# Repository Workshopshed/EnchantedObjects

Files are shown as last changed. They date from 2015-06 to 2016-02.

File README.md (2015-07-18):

# EnchantedObjects
The Enchanted Objects Design Challege asks 15 competitors to enchant an every day object.
http://www.element14.com/community/community/design-challenges/enchanted-objects

# The enchanted cottage
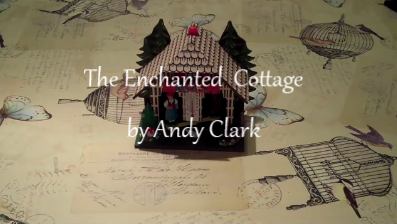
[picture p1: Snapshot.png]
The Enchanted Cottage


This particular enchanted object is right out of the storybooks. Deep in the forest is a small cottage owned by a timeless couple, Hans and Matilda who are doomed never to meet. When it is wet he goes outside but when it is dry she must leave the house.

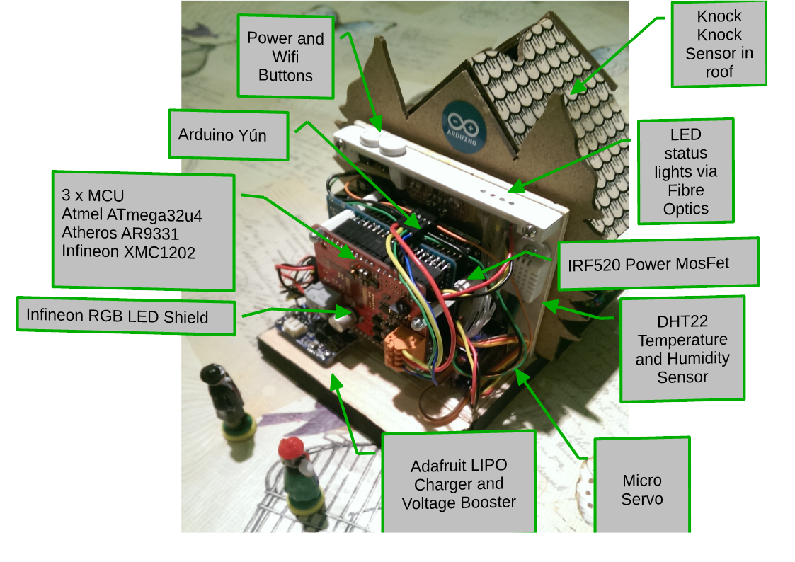
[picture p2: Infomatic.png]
System Overview


Their house may look traditional but is full of state of the art electronics. Thanks to their Arduino Yun they can receive their weather reports from the internet. And rather than their motion being powered by catgut they are now servo assisted. The inside of their house is lit with a colour changing LED which shows the status and temperature.

http://www.element14.com/community/community/design-challenges/enchanted-objects/blog/authors/Workshopshed

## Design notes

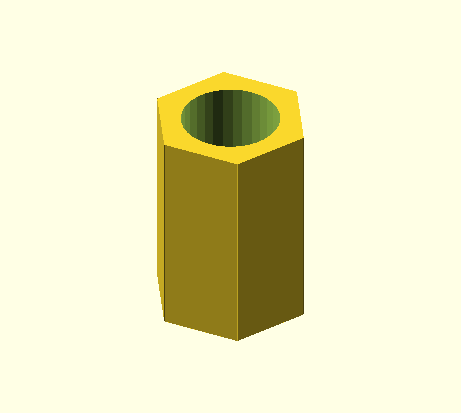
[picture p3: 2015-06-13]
Mechanics/Spacer.png

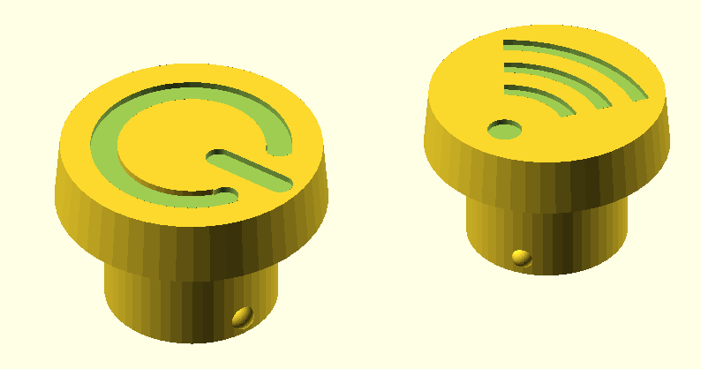
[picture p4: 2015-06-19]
Mechanics/Buttons.png

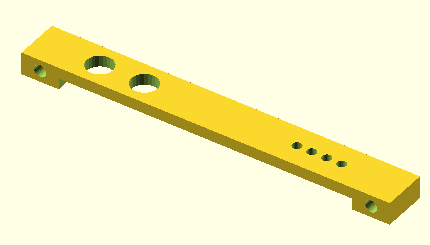
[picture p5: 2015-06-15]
Mechanics/TopPanel.png

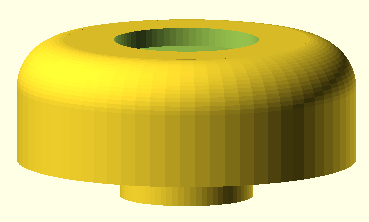
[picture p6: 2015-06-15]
Mechanics/MagnetHousing.png

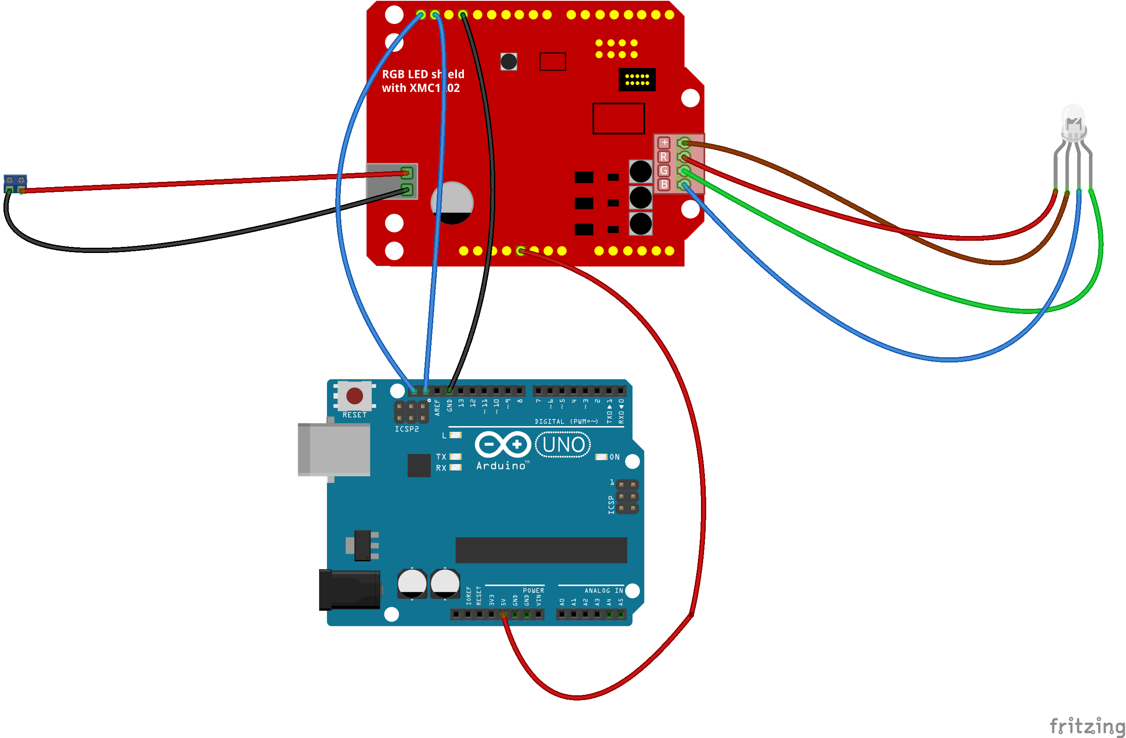
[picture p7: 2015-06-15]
Electronics/RGB Demo_bb.png

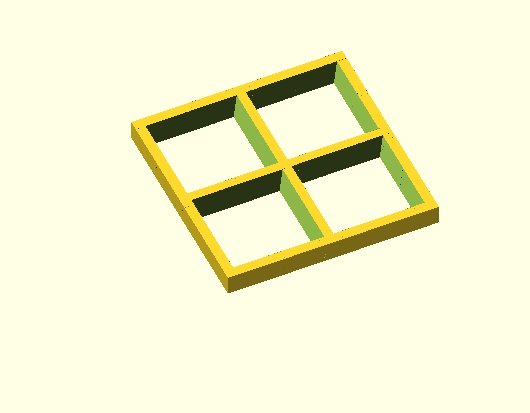
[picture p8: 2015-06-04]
Mechanics/WindowFrame.png

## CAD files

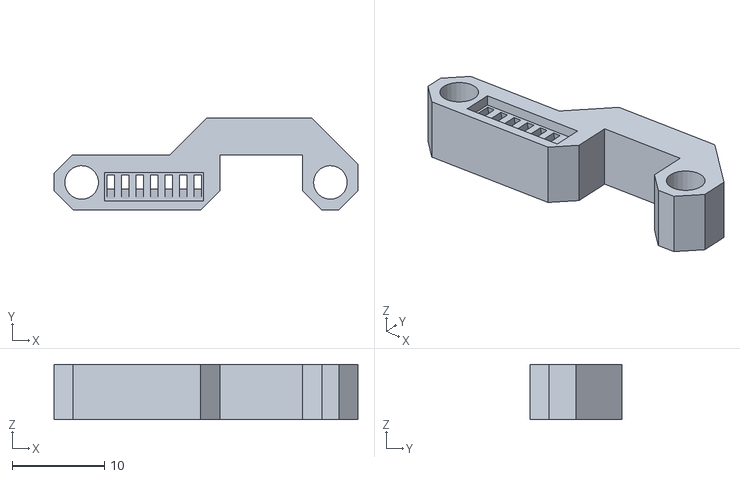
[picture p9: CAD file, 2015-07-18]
Mechanics/FibreHousing.stl
33.0 x 10.0 x 6.00

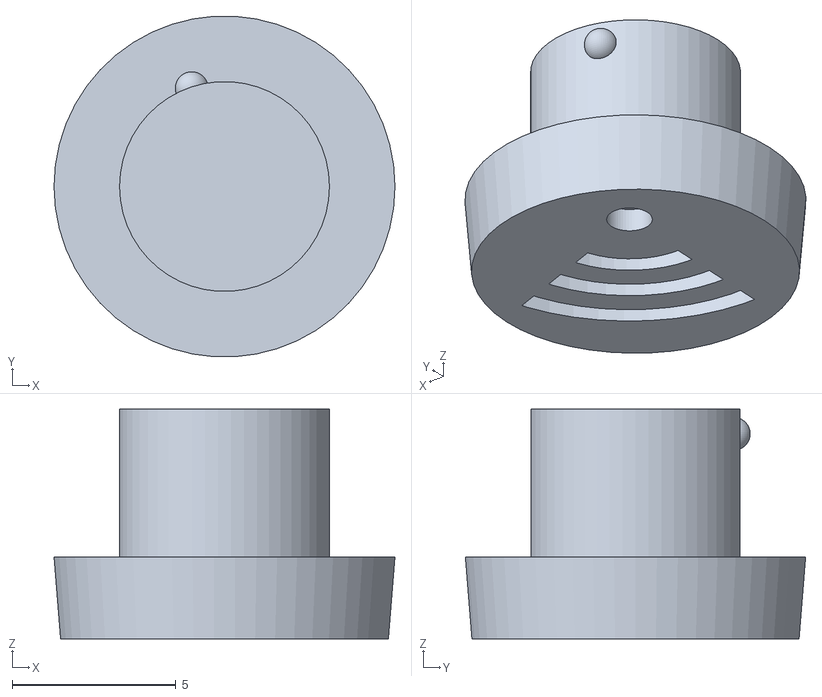
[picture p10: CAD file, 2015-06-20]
Mechanics/ButtonWifi.stl
10.4 x 10.4 x 7.00

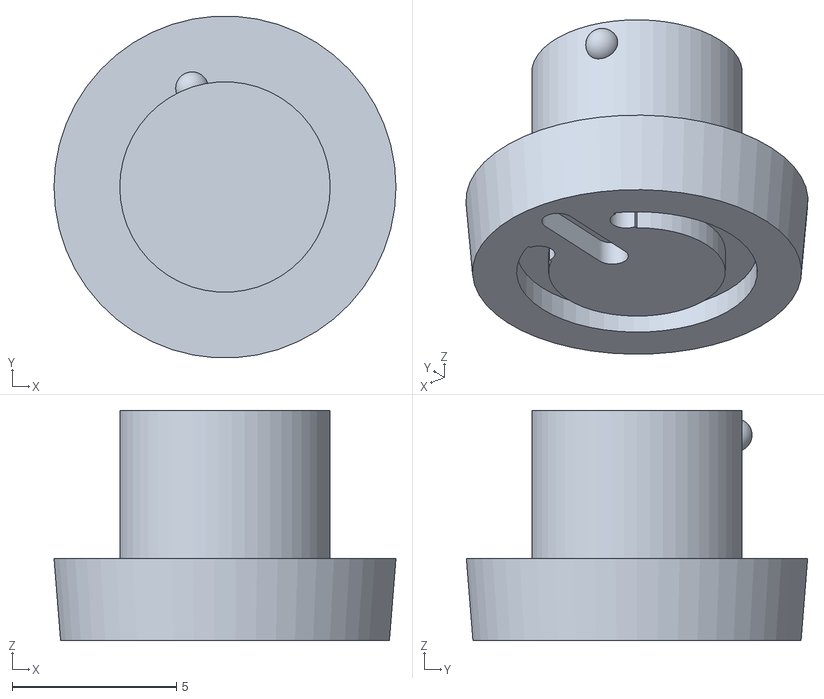
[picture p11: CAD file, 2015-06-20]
Mechanics/ButtonPower.stl
10.4 x 10.4 x 7.00

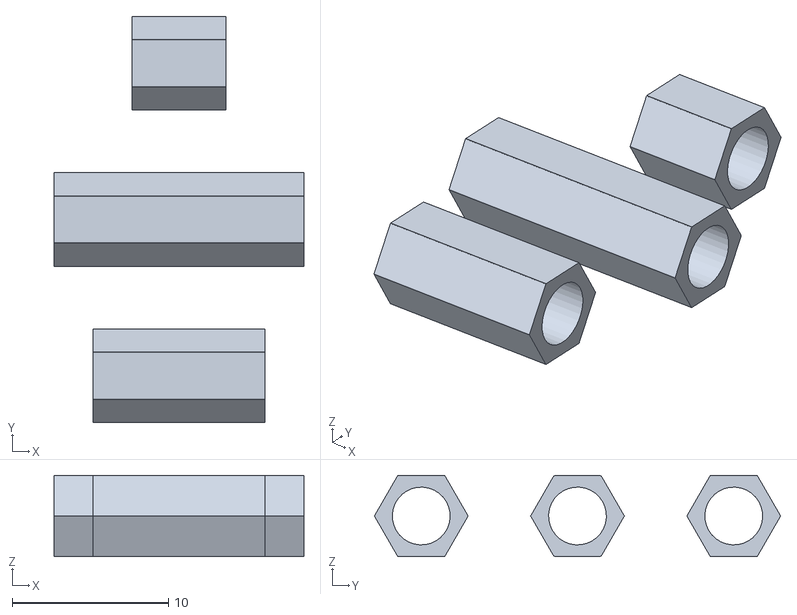
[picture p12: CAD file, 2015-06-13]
Mechanics/Spacers.stl
16.0 x 26.0 x 5.20

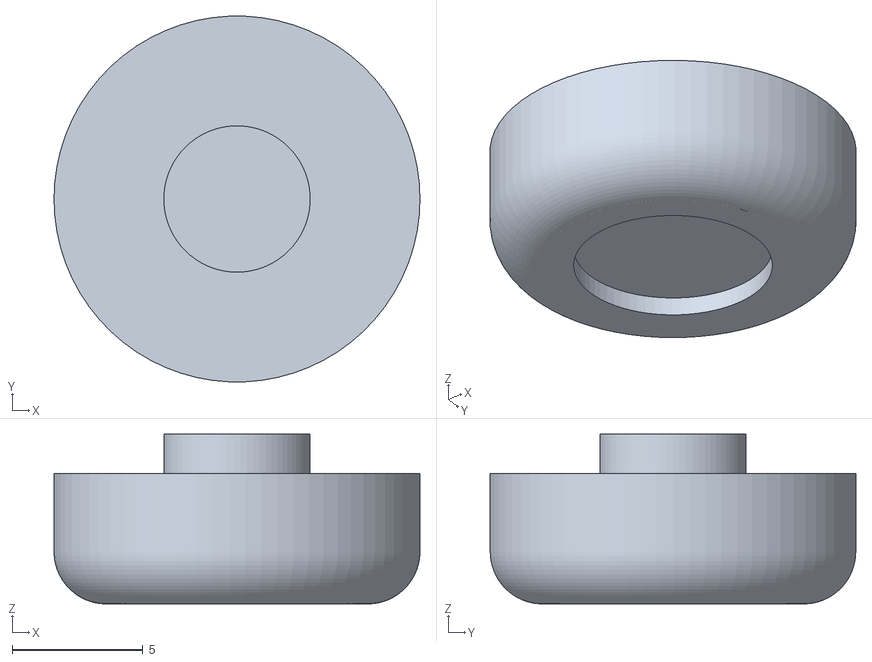
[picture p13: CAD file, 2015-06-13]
Mechanics/MagnetHousing.stl
14.0 x 14.0 x 6.50

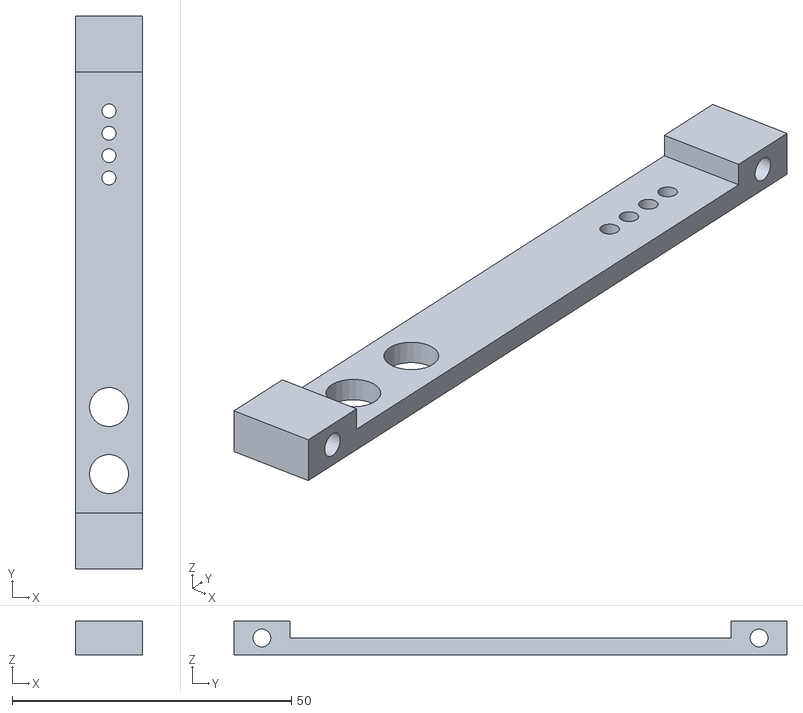
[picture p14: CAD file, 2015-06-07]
Mechanics/TopPanel.stl
12.0 x 99.0 x 6.00

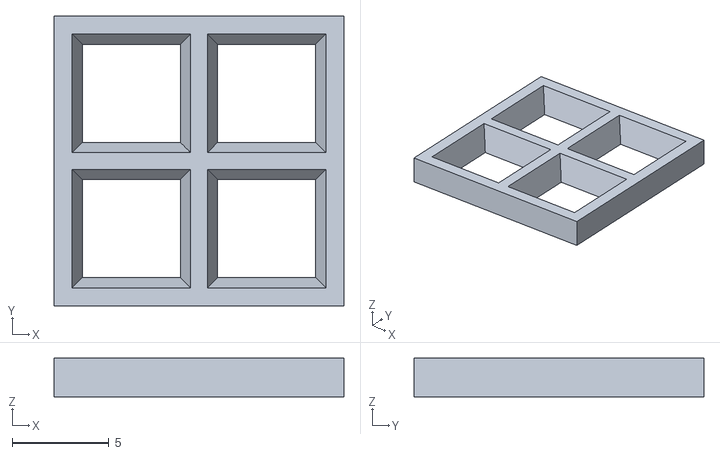
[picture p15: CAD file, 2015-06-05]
Mechanics/WindowFrame.stl
15.0 x 15.0 x 2.00

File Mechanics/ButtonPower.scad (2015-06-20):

module logo(radius,height) {
	union() {
		del = 1;
		scale = (radius/5);
		band = scale / 2.5;
		angle = 32;
		//Arc
		difference() {
				cylinder(h=height,r=3*scale,center=true,$fn=50);
				cylinder(h=height+del,r=(3*scale)-2*band,center=true,$fn=50);
				translate([0,2.2*scale,0])
					cube(size = [2.7*scale,2.5*scale,height+del], center = true);
			}
		//Bar 
		translate([0,scale,-height/2])
			hull() {
				cylinder(h=height,r=band,centre=true,$fn=50);
				translate([0,2.2*scale,0])
					cylinder(h=height,r=band,centre=true,$fn=50);
			}
		translate([sin(-angle)*((3*scale)-band),cos(-angle)*((3*scale)-band),0])
			cylinder(h=height,r=band,center=true,$fn=50);
	    translate([sin(angle)*((3*scale)-band),cos(angle)*((3*scale)-band),0])
			cylinder(h=height,r=band,center=true,$fn=50);
					
	}
}

module button_power() {
	union() {
		//Cap
		difference () {
			cylinder(h=2.5,r1=5.2,r2=5,center=true,$fn=50);
			translate([0,0,1.5])
				logo(6.1,2);
		}
		//Shank
		translate([0,0,-3])
			cylinder(h=5.5,r=3.2,center=true,$fn=50);
		translate([1,3,-5.0])
			sphere(0.5,$fn=50);
	}
}

rotate([0,180,0])
	button_power();

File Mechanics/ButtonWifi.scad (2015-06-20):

module wifi(radius,height) {
	union() {
		del = 1;
		band = 0.45;
		scale = (radius/4);
		difference () {
			for ( i = [2 : 4] ) {
				difference() {
					cylinder(h=height,r=i*scale,center=true,$fn=50);
					cylinder(h=height+del,r=(i-band)*scale,center=true,$fn=50);
				}
			}
			translate([2.5*scale,0,0])
				cube(size = [5*scale,9*scale,height+del], center = true);
			rotate([0,0,20])
				translate([0,2.5*scale,0])
					cube(size = [9*scale,5*scale,height+del], center = true);
		}
		cylinder(h=height,r=band*(radius/4),center=true,$fn=50);
	}
}

module button_wifi() {
	union() {
		//Cap
		difference () {
			cylinder(h=2.5,r1=5.2,r2=5,center=true,$fn=50);
			translate([1.8,2.6,1.5])
				wifi(6.2,2);
		}
		//Shank
		translate([0,0,-3])
			cylinder(h=5.5,r=3.2,center=true,$fn=50);
		translate([1,3,-5.0])
			sphere(0.5,$fn=50);
	}
}

rotate([0,180,0])
	button_wifi();

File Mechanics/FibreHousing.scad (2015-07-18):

module housing(thickness)
{
	difference() {
	cube([33,10,thickness]);
		translate([20.5,6,-1])
			cube([18,10,thickness+2]);
	//Debugging Socket	
	translate([6,-1,-1])
		cube([9,7,thickness+2]);
	//Champhered Corners	
	translate([0,5,-1])
		rotate([0,0,45])
		cube([10,6,thickness+2]);
	translate([27,10,-1])
		rotate([0,0,-45])
		cube([10,5,thickness+2]);
	translate([30.5,-7.5,-1])
		rotate([0,0,45])
		cube([10,5,thickness+2]);
	translate([3.5,-7.5,-1])
		rotate([0,0,45])
		cube([10,5,thickness+2]);		
	translate([-5.5,0.5,-1])
		rotate([0,0,-45])
		cube([10,5,thickness+2]);
	translate([9.5,0.5,-1])
		rotate([0,0,-45])
		cube([10,5,thickness+2]);
	translate([24,9.5,-1])
		rotate([0,0,135])
		cube([10,5,thickness+2]);

	//Mounting Holes
	translate([3,3,thickness/2])
		cylinder(d=3.65,h=thickness+2,center=true,$fn=25);
	translate([30,3,thickness/2])
		cylinder(d=3.65,h=thickness+2,center=true,$fn=25);
	//Light holes
	s = 11.0/7.0;
	for(i = [0:1:6]) 
		rotate([-12,0,0])
		translate([17+(i*s),1,-1])
		cube([0.8,2.5,thickness+3]);
	
	//Knockout for light housing
	translate([16.75,1,-1])
		cube([10.75,3.1,2]);
	}
}

rotate([0,180,0])
	housing(6);

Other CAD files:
Mechanics/MagnetHousing.scad
Mechanics/MechanismParts.scad
Mechanics/Spacer.scad
Mechanics/TopPanel.scad
Mechanics/WindowFrame.scad
Mechanics/Woodparts.scad

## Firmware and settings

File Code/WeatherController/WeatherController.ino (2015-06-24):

#include <Wire.h>
#include <avr/power.h>
#include "EnableInterrupt.h"
#include "LowPower.h"
#include "Controller.h"
#include "DHT.h"
#include "infineonrgb.h"
#include "VarSpeedServo.h"

const int DHTPIN = 4;
const int knockPin = 11;
#define DHTTYPE DHT22   // DHT 22  (AM2302)

DHT dht(DHTPIN, DHTTYPE);
VarSpeedServo servo;
InfineonRGB led;
Blinker blinker(0x0777,1);

CONTROLLER Controller(&dht,&servo,&led,&Serial1,&blinker);

void setup() {
  power_adc_disable();          //Not using any analogue functionality so can turn it off
  Serial.begin(115200);
  while (!Serial) {
     ; // wait for serial port to connect.
   }
  
  Serial1.begin(115200);
  Controller.begin();
  enableInterrupt(knockPin, knock, CHANGE);
}

void loop() {
  Controller.run();
}

void knock() {
  Controller.wake();
}

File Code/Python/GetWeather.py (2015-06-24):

# For Curl version
from StringIO import StringIO
import pycurl
import json, sys, urllib, urlparse
import subprocess
import serial
import os,signal,sys
from parse import *


def get_location():
    with open('/etc/WeatherAPI.conf', 'r') as f:
        # with open('WeatherAPI.conf', 'r') as f:
        location_name = f.readline()
    f.close()
    return location_name


def build_url(location):
    url = "https://query.yahooapis.com/v1/public/yql"
    q = "select item.condition from weather.forecast where woeid in (select woeid from geo.places(1) where text = '" + urllib.quote(
        location) + "') and u='c'"
    params = {'q': q, 'format': 'json', 'env': 'store://datatables.org/alltableswithkeys'}

    url_parts = list(urlparse.urlparse(url))
    query = dict(urlparse.parse_qsl(url_parts[4]))
    query.update(params)

    url_parts[4] = urllib.urlencode(query)

    return urlparse.urlunparse(url_parts)


def call_api(url):
    r = StringIO()
    c = pycurl.Curl()
    c.setopt(c.URL, url)
    c.setopt(c.CONNECTTIMEOUT, 10)
    c.setopt(c.TIMEOUT, 60)
    c.setopt(c.WRITEFUNCTION, r.write)
    c.perform()
    c.close()
    return r.getvalue()


def map_code(code):
    # Map condition codes to expected precipitation
    # https://developer.yahoo.com/weather/documentation.html
    # 1 = very sunny, 3 = changeable, 5 = very rainy
    codes = {'0': {'n': 'tornado', 'p': 3},
             '1': {'n': 'tropical storm', 'p': 5},
             '2': {'n': 'hurricane', 'p': 5},
             '3': {'n': 'severe thunderstorms', 'p': 5},
             '4': {'n': 'thunderstorms', 'p': 5},
             '5': {'n': 'mixed rain and snow', 'p': 5},
             '6': {'n': 'mixed rain and sleet', 'p': 5},
             '7': {'n': 'mixed snow and sleet', 'p': 5},
             '8': {'n': 'freezing drizzle', 'p': 5},
             '9': {'n': 'drizzle', 'p': 4},
             '10': {'n': 'freezing rain', 'p': 5},
             '11': {'n': 'showers', 'p': 4},
             '12': {'n': 'showers', 'p': 4},
             '13': {'n': 'snow flurries', 'p': 4},
             '14': {'n': 'light snow showers', 'p': 4},
             '15': {'n': 'blowing snow', 'p': 3},
             '16': {'n': 'snow', 'p': 4},
             '17': {'n': 'hail', 'p': 4},
             '18': {'n': 'sleet', 'p': 4},
             '19': {'n': 'dust', 'p': 3},
             '20': {'n': 'foggy', 'p': 4},
             '21': {'n': 'haze', 'p': 3},
             '22': {'n': 'smoky', 'p': 3},
             '23': {'n': 'blustery', 'p': 3},
             '24': {'n': 'windy', 'p': 3},
             '25': {'n': 'cold', 'p': 3},
             '26': {'n': 'cloudy', 'p': 3},
             '27': {'n': 'mostly cloudy (night)', 'p': 3},
             '28': {'n': 'mostly cloudy (day)', 'p': 3},
             '29': {'n': 'partly cloudy (night)', 'p': 3},
             '30': {'n': 'partly cloudy (day)', 'p': 3},
             '31': {'n': 'clear (night)', 'p': 1},
             '32': {'n': 'sunny', 'p': 1},
             '33': {'n': 'fair (night)', 'p': 2},
             '34': {'n': 'fair (day)', 'p': 2},
             '35': {'n': 'mixed rain and hail', 'p': 4},
             '36': {'n': 'hot', 'p': 1},
             '37': {'n': 'isolated thunderstorms', 'p': 4},
             '38': {'n': 'scattered thunderstorms', 'p': 4},
             '39': {'n': 'scattered thunderstorms', 'p': 4},
             '40': {'n': 'scattered showers', 'p': 4},
             '41': {'n': 'heavy snow', 'p': 5},
             '42': {'n': 'scattered snow showers', 'p': 4},
             '43': {'n': 'heavy snow', 'p': 5},
             '44': {'n': 'partly cloudy', 'p': 2},
             '45': {'n': 'thundershowers', 'p': 5},
             '46': {'n': 'snow showers', 'p': 5},
             '47': {'n': 'isolated thundershowers', 'p': 4}}
    state = codes.get(code)
    if not state:
        raise RuntimeError('Unknown weather code returned')
    return state['p']


def parse_weather(json):
    text = json['query']['results']['channel']['item']['condition']['text'].replace(",", " ")
    code = map_code(json['query']['results']['channel']['item']['condition']['code'])
    temp = json['query']['results']['channel']['item']['condition']['temp']
    return {'text': text, 'code': code, 'temp': float(temp)}


def guess_weather(rel_humidity, temp):
    # Temperature in Degrees C and Relative Humidity as a percentage
    # Based on an approximation of these graphs
    # ftp://www.star.nesdis.noaa.gov/pub/smcd/spb/lzhou/AMS86/PREPRINTS/PDFS/97921.pdf
    if rel_humidity < 0.66 * temp + 53:
        weather = 1  # Very likely dry
    elif rel_humidity < 0.66 * temp + 63:
        weather = 2
    elif rel_humidity < 0.66 * temp + 73:
        weather = 3  # Changeable
    elif rel_humidity < 0.66 * temp + 83:
        weather = 4
    elif rel_humidity >= 0.66 * temp + 83:
        weather = 5  # Probably rainy
    return {'text': "Local Estimate", 'code': weather, 'temp': float(temp)}


def parselines(s):
    lines = s.splitlines()
    d = {}
    for line in lines:
        p = parse("{}: {}", line)
        if p:
            d[p[0]] = p[1]
    return d


def getWifiStatus():
    # w = subprocess.check_output(["type", "WifiExample.txt"], shell=True)  # Shell needed for type command, should not be needed for running Prettyprint
    w = subprocess.check_output("/usr/bin/pretty-wifi-info.lua")
    p = parselines(w)

    for key in (
    'Mode', 'Interface name', 'SSID', 'Signal', 'Encryption method', 'Active for', 'IP address', 'MAC address',
    'RX/TX'):
        p.setdefault(key, 'Unknown')

    return p

def getWeather(humid, temp):
    try:
        w = getWifiStatus()
        if w['Mode'] == "Client":
            loc = get_location()
            weather_url = build_url(loc)
            r = call_api(weather_url)
            j = json.loads(r)
            weather = parse_weather(j)
            return 'OK!,%s,%s,%4.2f' % (weather['text'], weather['code'], weather['temp'])
        else:
            weather = guess_weather(humid, temp)
            return 'CLI,%s,%s,%4.2f' % (weather['text'], weather['code'], weather['temp'])

    except Exception, err:
        weather = guess_weather(humid, temp)
        return 'ERR,%s,%s,%4.2f' % (str(err).replace(",", " "), weather['code'], weather['temp'])


def processSerial(line):
    # Expect lines in similar format as outbound 'OK!,temp,humidity'
    default_temp = 10
    default_humid = 70

    if line[0:2] != "OK!":
        return {'temp': default_temp, 'humid': default_humid}
    s = line.split(',')
    if len(s) < 3:
        return {'temp': default_temp, 'humid': default_humid}

    temp = s[1]
    humid = s[2]

    return {'temp': temp, 'humid': humid}
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

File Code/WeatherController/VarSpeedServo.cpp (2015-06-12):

/*
 Servo.cpp - Interrupt driven Servo library for Arduino using 16 bit timers- Version 2
 Copyright (c) 2009 Michael Margolis.  All right reserved.
 
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
 You should have received a copy of the GNU Lesser General Public
 License along with this library; if not, write to the Free Software
 Foundation, Inc., 51 Franklin St, Fifth Floor, Boston, MA  02110-1301  USA
 */

/*
  Function slowmove and supporting code added 2010 by Korman. Above limitations apply
  to all added code, except for the official maintainer of the Servo library. If he,
  and only he deems the enhancment a good idea to add to the official Servo library,
  he may add it without the requirement to name the author of the parts original to
  this version of the library.
*/

/*
  Updated 2013 by Philip van Allen (pva), 
  -- updated for Arduino 1.0 +
  -- consolidated slowmove into the write command (while keeping slowmove() for compatibility
     with Korman's version)
  -- added wait parameter to allow write command to block until move is complete
  -- added sequence playing ability to asynchronously move the servo through a series of positions, must be called in a loop

  A servo is activated by creating an instance of the Servo class passing the desired pin to the attach() method.
  The servos are pulsed in the background using the value most recently written using the write() method

  Note that analogWrite of PWM on pins associated with the timer are disabled when the first servo is attached.
  Timers are seized as needed in groups of 12 servos - 24 servos use two timers, 48 servos will use four.
  The sequence used to sieze timers is defined in timers.h

  The methods are:

   VarSpeedServo - Class for manipulating servo motors connected to Arduino pins.

   attach(pin )  - Attaches a servo motor to an i/o pin.
   attach(pin, min, max  ) - Attaches to a pin setting min and max values in microseconds
   default min is 544, max is 2400  
 
   write(value)     - Sets the servo angle in degrees.  (invalid angle that is valid as pulse in microseconds is treated as microseconds)
   write(value, speed) - speed varies the speed of the move to new position 0=full speed, 1-255 slower to faster
   write(value, speed, wait) - wait is a boolean that, if true, causes the function call to block until move is complete

   writeMicroseconds() - Sets the servo pulse width in microseconds 
   read()      - Gets the last written servo pulse width as an angle between 0 and 180. 
   readMicroseconds()  - Gets the last written servo pulse width in microseconds. (was read_us() in first release)
   attached()  - Returns true if there is a servo attached. 
   detach()    - Stops an attached servos from pulsing its i/o pin. 

   slowmove(value, speed) - The same as write(value, speed), retained for compatibility with Korman's version

   stop() - stops the servo at the current position

   sequencePlay(sequence, sequencePositions); // play a looping sequence starting at position 0
   sequencePlay(sequence, sequencePositions, loop, startPosition); // play sequence with number of positions, loop if true, start at position
   sequenceStop(); // stop sequence at current position

 */

#include <avr/interrupt.h>
#include <Arduino.h> // updated from WProgram.h to Arduino.h for Arduino 1.0+, pva

#include "VarSpeedServo.h"

#define usToTicks(_us)    (( clockCyclesPerMicrosecond()* _us) / 8)     // converts microseconds to tick (assumes prescale of 8)  // 12 Aug 2009
#define ticksToUs(_ticks) (( (unsigned)_ticks * 8)/ clockCyclesPerMicrosecond() ) // converts from ticks back to microseconds


#define TRIM_DURATION       2                               // compensation ticks to trim adjust for digitalWrite delays // 12 August 2009

//#define NBR_TIMERS        (MAX_SERVOS / SERVOS_PER_TIMER)

static servo_t servos[MAX_SERVOS];                          // static array of servo structures
static volatile int8_t Channel[_Nbr_16timers ];             // counter for the servo being pulsed for each timer (or -1 if refresh interval)

uint8_t ServoCount = 0;                                     // the total number of attached servos

// sequence vars

servoSequencePoint initSeq[] = {{0,100},{45,100}};

//sequence_t sequences[MAX_SEQUENCE];

// convenience macros
#define SERVO_INDEX_TO_TIMER(_servo_nbr) ((timer16_Sequence_t)(_servo_nbr / SERVOS_PER_TIMER)) // returns the timer controlling this servo
#define SERVO_INDEX_TO_CHANNEL(_servo_nbr) (_servo_nbr % SERVOS_PER_TIMER)       // returns the index of the servo on this timer
#define SERVO_INDEX(_timer,_channel)  ((_timer*SERVOS_PER_TIMER) + _channel)     // macro to access servo index by timer and channel
#define SERVO(_timer,_channel)  (servos[SERVO_INDEX(_timer,_channel)])            // macro to access servo class by timer and channel

#define SERVO_MIN() (MIN_PULSE_WIDTH - this->min * 4)  // minimum value in uS for this servo
#define SERVO_MAX() (MAX_PULSE_WIDTH - this->max * 4)  // maximum value in uS for this servo 

/************ static functions common to all instances ***********************/
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

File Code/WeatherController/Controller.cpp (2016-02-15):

#include "Controller.h"

CONTROLLER::CONTROLLER(DHT *dht,VarSpeedServo *servo,InfineonRGB *led,Stream *serial,Blinker *blinker){
  _dht = dht;
  _servo = servo;
  _led = led;
  _serial = serial;
  _blinker = blinker;
  position = 1; // Middle position
  knock = false;
}

void CONTROLLER::begin() {
    pinMode(LEDPin, OUTPUT);
    pinMode(LininoPin, OUTPUT);
    pinMode(PowerPin, OUTPUT);
    pinMode(HandshakePin, INPUT);
    pinMode(ButtonPowerPin, INPUT_PULLUP);
    pinMode(ButtonWifiPin, INPUT_PULLUP);
    _blinker->SetColour(White);
    //Servo pin is handled by servo attach
}

void CONTROLLER::run(void) {
          switch (state) {
          case C_Sleeping:
              if (sleeps <= 0 || knock) {
                  state = C_WakeUp;
              } else {
                //Don't sleep if the user is pressing the power pin
                if (!digitalRead(ButtonPowerPin)) {
                  sleeps--;
                  sleep();
                }
              }
              break;
          case C_WakeUp:
              Serial.println("Waking up");
              acknowledge();
              _blinker->Blink(Blink_Long);
              lininoOn();
              powerOn();
              moveServo(); // Show previous values
              readLocalWeather();
              state = C_Booting;
              break;
          case C_Booting:
              if (isLininoRunning()) {
                Serial.println("Getting Weather");
                requestNetWeather();
                state = C_GettingWeather;
              }
              break;
          case C_GettingWeather:
              if (isReadyNetWeather()) {
                Serial.println("Parsing Weather");
                if (!readNetWeather()) { break;} 
                lininoOff();
                moveServo();
                state = C_Display;
                _DisplayTimeout = millis() + 60000; // Display for 1 minute
              }
              break;
           case C_Display:
             if (_DisplayTimeout < millis()) {
               Serial.println("Back to sleep");
               _blinker->Blink(Blink_Off);
               powerOff();
               //sleeps = 15; //1 min
               sleeps = 900; // (60/4)*60 = 60 minutes of sleep
               knock = false;               
               state = C_Sleeping;
             }
             break;
        }
        setLED(); 
}

void CONTROLLER::readLocalWeather() {
    // Reading temperature or humidity takes about 250 milliseconds!
    // Sensor readings may also be up to 2 seconds 'old' (its a very slow sensor)
    localhumidity = _dht->readHumidity();
    localtemp = _dht->readTemperature();
};

void CONTROLLER::requestNetWeather() {
  delay(250); //Give Python time to start up
  flushserial();
  //Request new forecast
  _serial->print("OK!,");
  _serial->print(localtemp);
  _serial->print(",");
  _serial->print(localhumidity);
  _serial->print("\n");
}


bool CONTROLLER::isReadyNetWeather() {
   return (_serial->available() > 0); 
}

bool CONTROLLER::readNetWeather() {
  // This is a blocking read so call isReadyNetWeather() first;
  // Read weather over /dev/ttyATH0<->Serial1
  String weather = _serial->readStringUntil('\n');
  
  //String weather = "OK!,Cloudy,3,19.00"; //Check,Status,Position,Temperature

  //Not enought data
  if (weather.length() < 3) {  // Something went wrong
      state = C_Booting; //Try again
      _blinker->Blink(Blink_Short);
      return false;
  } 
  
  //Data garbled
  if (!weather.startsWith("OK!") && !weather.startsWith("CLI") && !weather.startsWith("CLI")) {
      state = C_Booting; //Try again
      _blinker->Blink(Blink_Short);
      return false;
  }     
  
  Serial.println(weather);
  
  if (weather.startsWith("ERR"))  { _blinker->Blink(Blink_Short); }
  if (weather.startsWith("CLI"))  { _blinker->Blink(Blink_Cycle); }
  if (weather.startsWith("OK!"))  { _blinker->Blink(Blink_Solid); }

  parseWeather(weather);
  
  return true;
}

bool CONTROLLER::parseWeather(String weather) {
  bool changed = false;
  
  const char separator = ',';
  unsigned int c1 = weather.indexOf(separator);
  unsigned int c2 = weather.indexOf(separator, c1+1);
  unsigned int c3 = weather.indexOf(separator, c2+1);
  // Check if we have 4 values separated with commas
  if (c1 == -1 || c2 == -1 || c3 == -1) { return changed; }

  String sPos = weather.substring(c2+1,c3);
  uint8_t tempPos = sPos.toInt();
  if (tempPos != 0) {
    if (tempPos != position) {
      changed = true;
      position = tempPos;
    }
  }

  String sTemp = weather.substring(c3+1);
  float tempTemp = sTemp.toFloat();
  if (tempTemp != 0) {
    if (nettemp != tempTemp) {
      changed = true;
      nettemp = tempTemp;
    }
  }
  return changed;
}

void CONTROLLER::powerOn() {
    digitalWrite(PowerPin, HIGH);    // sets the MOSFET on
    _servo->attach(ServoPin);
    if (_servo->read() == 0) { _servo->write(ServoMid,10,false); };
    _dht->begin();                  
    _led->begin();                //Todo: This calls wire.begin, any issues doing that?
    _led->SetCurrentRGB(1,1,1);
    _led->SetOffTimesRGB(0x50, 0x52,0x50);
    _led->SetDimmingLevel(0);       // Off
}

void CONTROLLER::powerOff() {
    _servo->stop();
    _servo->detach();
    digitalWrite(PowerPin, LOW);    // sets the MOSFET off
}

void CONTROLLER::lininoOn() {
    digitalWrite(LininoPin, HIGH);    // sets the Linino on
}

void CONTROLLER::lininoOff() {
    if (!digitalRead(ButtonPowerPin)) {return;} // Don't power off if the power button is pressed
    digitalWrite(LininoPin, LOW);    // sets the Linino off
}

bool CONTROLLER::isLininoRunning() {
  // See https://gist.github.com/wayoda/db3c023417757f726088
    return digitalRead(HandshakePin);
}

void CONTROLLER::moveServo() {
    uint8_t p = position;
    if (p == 0) { p = 3; }           // Default to middle position
    p = constrain(position, 1, 5);   // Ensure position valid
    unsigned int degrees = map(p,1,5,ServoMin,ServoMax); // Move servo to correct position 50 to 100 degrees
    _servo->write(degrees,10,false); // Slow move, don't wait
}

void CONTROLLER::setLED() {
     if (nettemp <= 0)                  { _blinker->SetColour(White);  }
     if (nettemp > 0  && nettemp <= 5)  { _blinker->SetColour(Purple); }
     if (nettemp > 5  && nettemp <= 10) { _blinker->SetColour(Blue);   }
     if (nettemp > 10 && nettemp <= 15) { _blinker->SetColour(Green);  }
     if (nettemp > 15 && nettemp <= 25) { _blinker->SetColour(Yellow); }
     if (nettemp > 25 && nettemp <= 30) { _blinker->SetColour(Orange); }
     if (nettemp > 30 )                 { _blinker->SetColour(Red);    }

     _led->SetDimmingLevel(_blinker->Level());
     _led->SetColor(_blinker->GetColour());
}

void CONTROLLER::sleep() {
     LowPower.powerDown(SLEEP_8S, ADC_OFF, BOD_OFF);
}

void CONTROLLER::wake() {
    //Called by interupt, keep as short as possible
    knock = true;
}
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

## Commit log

2015-03-25 Experimental Models
    [Beam.scad, BeamWithRivets.scad, BeamWithRivets.stl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]
2015-03-25 Removed more material from rivets
    [BeamWithRivets.stl]
2015-03-25 Adjusted removed material
    [BeamWithRivets.scad, BeamWithRivets.stl]
2015-03-25 Smaller head
    [BeamWithRivets.scad, BeamWithRivets.stl]
2015-03-25 Rounder rivets
    [BeamWithRivets.scad, BeamWithRivets.stl]
2015-03-25 Folder rename
    [Beam.scad, BeamWithRivets.scad, BeamWithRivets.stl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]
2015-03-28 new models
    [BeamWithPins.scad, BeamWithPins.stl, BeamWithPinsTest.stl]
2015-03-28 Fix for floating washers
    [BeamWithPins.scad, BeamWithPinsTest.stl, Washer.stl]
2015-03-29 More prints
    [6Washers.stl, BatchPrint.stl, BeamWithPins.scad]
2015-03-29 Long Plate
    [BeamWithPins.scad, LongPlate.stl]
2015-04-04 Updated plates
    Thicker plates
    Adjusted lengths and pin positions
    [BatchPrint.stl, BeamWithPins.scad, Plates.stl]
2015-04-04 Wood parts
    [Woodparts.scad]
2015-04-04 Woodparts
    Changed to be a module
    [Woodparts.scad]
2015-04-05 Plates thicker
    [BeamWithPins.scad, Plates.stl]
2015-04-12 Holes experiment
    Holes but not all the way through
    [6Washers.stl, BeamWithPins.scad, Plates.stl]
2015-05-09 Fibre Optic Housing
    [FibreHousing.scad]
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2015-05-15 Certs from OpenWRT
    Because we are using the standard Arduino package repository the
    certificates have moved
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2015-06-01 FibreHousing STL
    [FibreHousing.stl]
2015-06-02 Fibre Housing
    Fix position of LEDs and chop off a couple of corners
    [FibreHousing.scad]
2015-06-02 Fibre Housing Model
    Updated STL
    [FibreHousing.stl]
2015-06-04 Window Frame
    [WindowFrame.scad, WindowFrame.stl]
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2015-06-05 Fibre Housing
    Updated shape and chamfers
    [FibreHousing.scad, FibreHousing.stl]
2015-06-05 Top Panel
    First draft
    [TopPanel.scad]
2015-06-05 Frame to 15mm
    [WindowFrame.scad, WindowFrame.stl]
2015-06-05 Fibre Housing
    More fillets and larger holes
    [FibreHousing.scad, FibreHousing.stl]
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2015-06-06 Top Panel
    Switches and Fibreholes
    [TopPanel.scad, TopPanel.stl]
2015-06-06 Fibre Housing
    Holes and slot for LEDs
    [FibreHousing.scad, FibreHousing.stl]
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2015-06-07 Top Panel
    Increased spacing on switches
    [TopPanel.scad, TopPanel.stl]
2015-06-07 Fibre Housing
    Increased cutout size to ensure no clash with LEDs
    [FibreHousing.scad, FibreHousing.stl]
2015-06-11 Magnet Housing
    [MagnetHousing.scad, MagnetHousing.stl]
2015-06-13 Spacer
    Simple spacer
    [Spacer.scad, Spacer8.stl]
2015-06-13 Magnet 8.2mm
    [MagnetHousing.scad, MagnetHousing.stl]
2015-06-13 Spacer with supports
    [Spacer.scad, Spacers.stl]
2015-06-13 Spacers with supports 2
    [Spacer.scad, Spacers.stl]
2015-06-13 Spacers
    Made them lying down
    [Spacer.scad, Spacers.stl]
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2015-06-15 Magnet Carriers
    Updated Magnet carriers to have hole towards one end
    [MagnetCarriers2.stl, MechanismParts.scad]
2015-06-15 Added ADC off
    Don't need Analogue features so turn them off
2015-06-18 Get Weather
    Fixes to string vs Number
    [GetWeather.py]
2015-06-18 Wifi Button
    [ButtonPower.scad, ButtonWifi.scad, ButtonWifi.stl]
2015-06-18 Power Button
    [ButtonPower.scad, ButtonPower.stl]
2015-06-18 Wifi Button
    Make button thinner
    [ButtonWifi.scad, ButtonWifi.stl]
2015-06-18 Power Button
    Thinned cap
    [ButtonPower.scad, ButtonPower.stl]
2015-06-18 Wifi Button
    Fine tuning
    [ButtonWifi.scad, ButtonWifi.stl]
2015-06-18 Power Button
    Fine Tuning
    [ButtonPower.scad, ButtonPower.stl]
2015-06-18 Wifi Button
    More Tweeks
    [ButtonWifi.scad, ButtonWifi.stl]
2015-06-18 Power Button
    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
    [ButtonPower.scad, ButtonPower.stl]
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2015-06-18 Wifi Button
    Reduced Logo Size
    [ButtonWifi.scad, ButtonWifi.stl]
2015-06-18 Power Button
    Reduced shank just a fraction
    [ButtonPower.scad, ButtonPower.stl]
2015-06-18 Wifi Button
    Reduced Shank just a little
    [ButtonWifi.scad, ButtonWifi.stl]
2015-06-19 Power Button
    Logo a little smaller
    [ButtonPower.scad, ButtonPower.stl]
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2015-06-19 Serial Echo
    Arduino and Python scripts to bounce back and forth
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2015-06-20 Power Button
    Increased embossing
    [ButtonPower.scad, ButtonPower.stl]
2015-06-20 Wifi Button
    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
    [ButtonWifi.scad, ButtonWifi.stl]
2015-06-21 Tidy Up
    Old parts and models that were not used
    [6Washers.stl, BatchPrint.stl, Beam.scad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]
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2015-06-23 Weather Controller
    Swapped in a stream variable into class initialiser
    [Controller.cpp, Controller.h, WeatherController.ino]
2015-06-23 Mechanics
    Tidy up
    [Horn.scad, LongPlate.stl, MagnetCarriers.stl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]
2015-06-23 Weather Controller
    Split out request weather into new function
    Added blinker to class init
    Added sleep counter (of int)
    Moved power_adc_disable into setup
    Added Sleep counter
2015-06-23 Class Diagram
    Updated to reflect current state of code
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2015-06-23 Knock and Buttons
    A test for the knock knock sensor and buttons
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2015-06-23 Weather Controller
    Power pin and knock pin were reversed
    [Controller.h, WeatherController.ino]
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2015-06-23 Servo Slow Sweep
    Added dwell to help diagnose
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2015-06-24 Weather Controller
    Fixed case
    Added isReadyNetWeather
    [Controller.cpp, Controller.h]
2015-06-24 Schematic
    Added Eagle file to the release
    [EnchantedCottage.sch]
2015-06-25 Wood Parts
    Change to reflect current
    [Woodparts.scad]
2015-06-26 Schematic
    Updated the labels
    [EnchantedCottage.sch]
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2015-07-18 Slimmed it down a bit
    [FibreHousing.scad, FibreHousing.stl]
2016-02-15 Parser fix
    Bug fix in parsing of temperature, was forgetting to remove comma
    [Controller.cpp]
